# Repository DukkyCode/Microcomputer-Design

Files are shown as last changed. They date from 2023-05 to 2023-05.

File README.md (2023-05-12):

# Microcomputer Design
Introduction:
-	The goal of this project is to design, build, and program a single-board computer. It also provides insight into computer architecture

Chip Specification:
- XR68C681CJ-F – DUART: the XR68C681 devices offers a single IC solution for the 68000 family of microprocessors.
- U62256ADK07LLG – RAM: Static RAM 32K x 8-Bit High Speed CMOS 150ns DIP -28
- AT28C256-15PU – ROM: Memory & Data Storage (EEPROM IC EEPROM 256k 50NS 28DIP) 
- Max232E: IC Transceiver 2 channel 16DIP to interface with DUART
- LD1085V50 – Voltage Regulator: Step 9V down to 5V to provide power for the entire board
- JS202011SCQN – Power Switch: Switch to turn on & off power
- B3F-1022 – Reset Button: Simple power button to activate RESET on the buttons
-	A-DS 09 A/KG-T2S – D-SUB connector: create serial communications with the desktop
-	PJ-002B – Barrel Plug: Barrel Connector to connect with power adapter
- ECS-2200B-080: Create 8MHz clock signal for the CPLD & CPU
- ECS-2100AX-036: Create 3.6MHz clock signal for the DUART chips
- 22-28-4061: J-TAG connector to program the CPLD

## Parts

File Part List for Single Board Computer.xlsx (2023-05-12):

Part | Part Number | Pins | Package | Quantity | Note | Reason | Part Links
Processor | MC68000FN10 | 68 | PLCC | 1 | Bought |  | https://www.ebay.com/itm/401212928938
CPLD | XC9572-10PC84C84 | 84 | PLCC | 1 | Bought |  | https://www.ebay.com/itm/1pcs-XC9572-7PC84C-PLCC-84-XC9572-In-System-Programmable-CPLD-/322563102028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
DUART | SCC68681C1A44 | 44 | PLCC | 1 | New site | The previous seller is out until close March | https://www.ebay.com/itm/392316632455
RAM | U62256ADK07LLG1 | 28 | DIP | 2 | New site | Unavailable | https://www.worldwayelec.com/pro/alliance-memory/u62256adk07llg1/337553?from=octopart
ROM | AT28C256-15PU | 28 | DIP | 2 | New site | Digikey has a different package type | https://www.mouser.com/ProductDetail/Omron-Automation-and-Safety/AT28C256-15PU-ND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
RS232 Driver | Max232E | 16 | DIP | 1 | Still available |  | https://www.digikey.com/en/products/detail/texas-instruments/MAX232ECN/1511013 (https://www.mouser.com/ProductDetail/STMicroelectronics/LD1085V50/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)
Voltage Regulator | LD1085V50 | 3 | THT | 1 | Still available |  | https://www.mouser.com/ProductDetail/STMicroelectronics/LD1085V50/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
Power Switch | JS202011SCQN | 6 | DIP | 1 | Still available |  | https://www.digikey.com/en/products/detail/c-k/JS202011SCQN/2094299
Reset Button | B3F-1022 | 4 | DIP | 1 | Still available |  | https://www.digikey.com/en/products/detail/omron-electronics-inc-emc-div/B3F-1022/44674
D-SUB Connector | A-DS 09 A/KG-T2S | 9 | DIP | 1 | Still available |  | https://www.digikey.com/en/products/detail/assmann-wsw-components/A-DS-09-A-KG-T2S/1241804
Barrel Plug | PJ-002B | 2 | DIP | 1 | Still available |  | https://www.digikey.com/en/products/detail/cui-inc/PJ-002B/96965
CPU/CPLD Clock | VF150-8.000000MHz | 4 | DIP | 1
DUART Clock | ECS-2100AX-036 | 4 | DIP | 1 | Still available |  | https://www.digikey.com/en/products/detail/ecs-inc/ECS-2100AX-036/827265
JTAG Connector | 22-28-4061 | 6 | DIP | 1 | New site |  | https://www.digikey.com/en/products/detail/molex/0022284061/313861?s=N4IgTCBcDa5gtGAHPALABgGwEYQF0BfIA
LEDs | APT3216QBC/D | 2 | SMD | 25 | Still available |  | https://www.mouser.com/ProductDetail/Kingbright/APT3216QBC-D?qs=sGAEpiMZZMseGfSY3csMkfEK84xZfg2SgloFr7gwbO4%3D
0805 1k Resistors | 603-RC0805FR-071KL | 2 | SMD | 20 | Still available |  | https://www.mouser.com/productdetail/yageo/rc0805fr-071kl?qs=sGAEpiMZZMvdGkrng054txdMlaQGj9fiG8OYDyT2iio%3D
0805 330 Resistors | RC0805FR-07330RL | 2 | SMD | 25 - for LEDs | New site | Old website out of stock | https://www.digikey.com/en/products/detail/yageo/RC0805FR-07330RL/727866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
0805 4.7k Resistors | RC0805FR-074K7L | 2 | SMD | 5 | New site | Old website out of stock | https://www.digikey.com/en/products/detail/yageo/RC0805FR-074K7L/727929
0805 1 uF Capacitors | CC0805KKX7R5BB105 | 2 | SMD | 20 | New site | Old website out of stock | https://www.digikey.com/en/products/detail/yageo/CC0805KKX7R5BB105/5884152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
0805 10 uF Capacitors | CC0805KFX5R5BB106 | 2 | SMD | 2 | New site | Old website out of stock | https://www.digikey.com/en/products/detail/yageo/CC0805KFX5R5BB106/14286468
Test Points | 5011 | 1 | DIP | 50 | Still available |  | https://www.digikey.com/products/en?keywords=36-5011-ND
Supervisor chips |  |  |  |  | Optional -depends if the class is using the supervisor chip in case of troubleshooting
Processor Socket | 8468-11B1-RK-TP | 68 | PLCC TO DIP | 1 | Still available |  | https://www.mouser.com/ProductDetail/3M-Electronic-Solutions-Division/8468-11B1-RK-TP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
CPLD Socket | 8484-11B1-RK-TP | 84 | PLCC TO DIP | 1 | Still available |  | https://www.mouser.com/ProductDetail/3M-Electronic-Solutions-Division/8484-11B1-RK-TP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
DUART Socket | 8444-11B1-RK-TP | 44 | PLCC TO DIP | 1 | Still available |  | https://www.mouser.com/ProductDetail/3M-Electronic-Solutions-Division/8444-11B1-RK-TP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
RAM Socket | 4-1571552-9 | 28 | DIP TO DIP | 2 | New site | Old website out of stock | https://www.digikey.com/en/products/detail/te-connectivity-amp-connectors/4-1571552-9/2055977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
ROM Socket | 228-3345 | 28 | DIP TO DIP - ZIF | 2 (comes in 2 pack) | New site - Limited Stock | Out of stock - Amazon $17 and Jameco $10 | https://www.amazon.com/Aries-28-526-10-Connector-Position-Through-Hole/dp/B00B886OLW | https://www.jameco.com/z/28-526-10-Aries-Electronics-ZIF-Socket-28-Position-2-54mm-Solder-Straight-Thru-Hole_102745.html
RS232 Driver Socket | 2-1571552-4 | 16 | DIP TO DIP | 1 | New site | Old website out of stock | https://www.ebay.com/itm/383202106349?hash=item5938a01bed:g:JvEAAOSwBzdgUdBe

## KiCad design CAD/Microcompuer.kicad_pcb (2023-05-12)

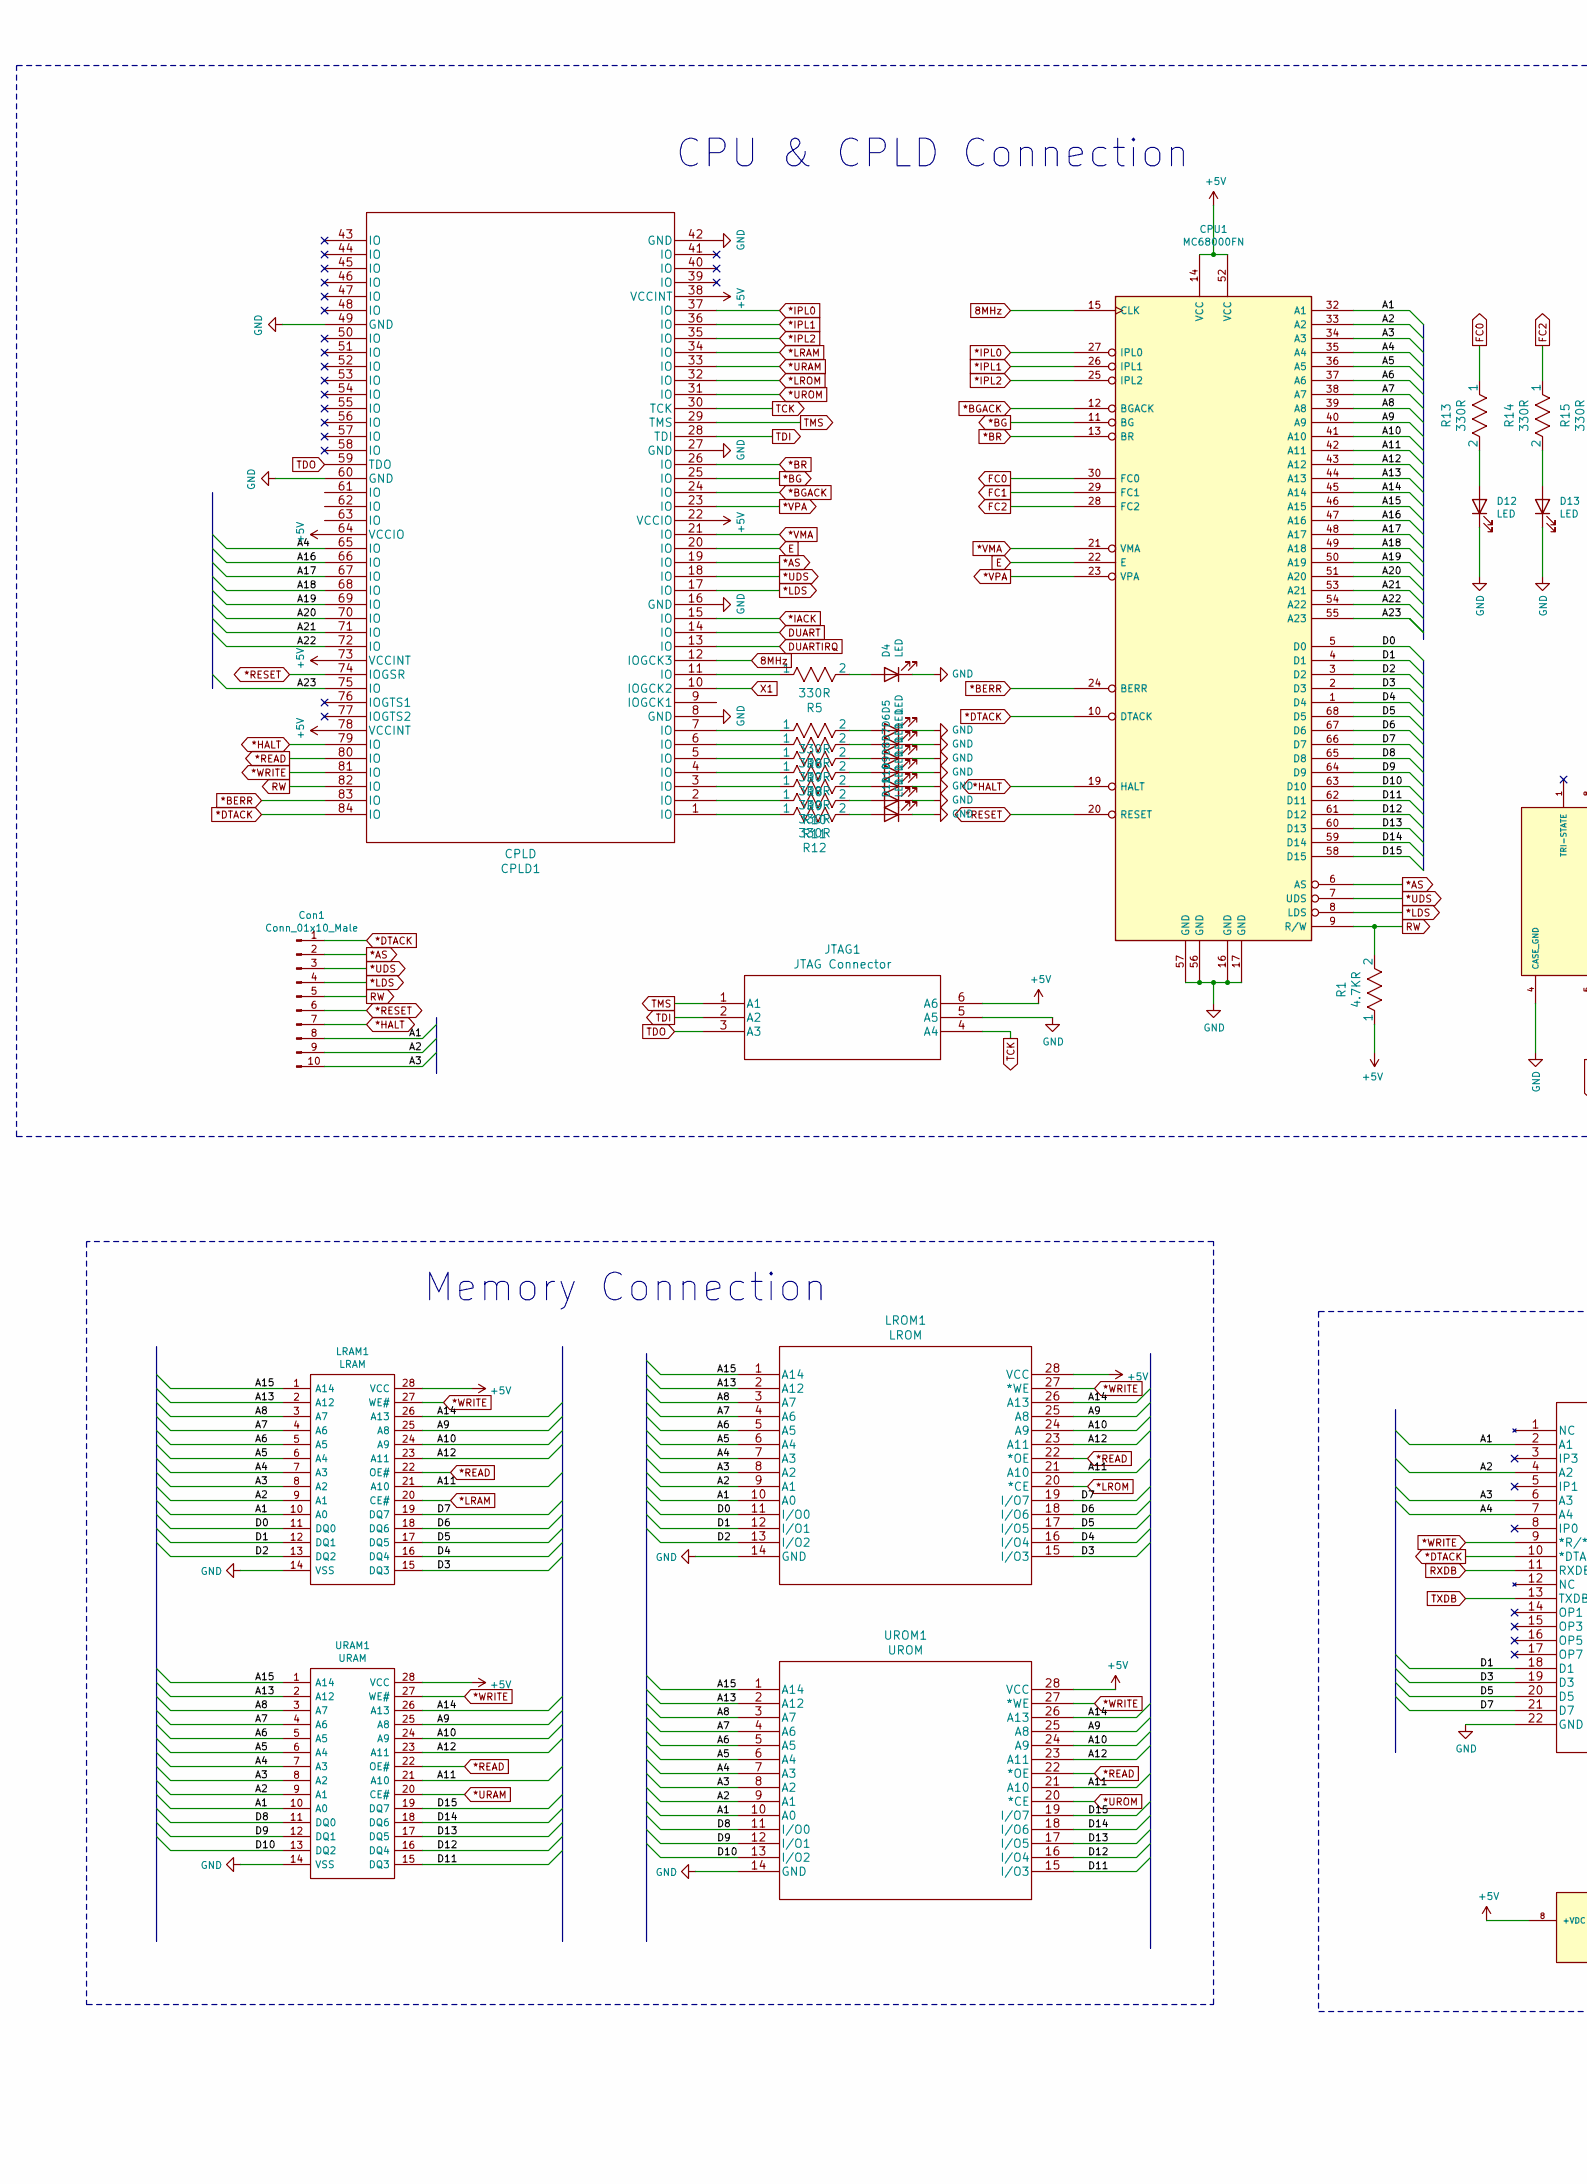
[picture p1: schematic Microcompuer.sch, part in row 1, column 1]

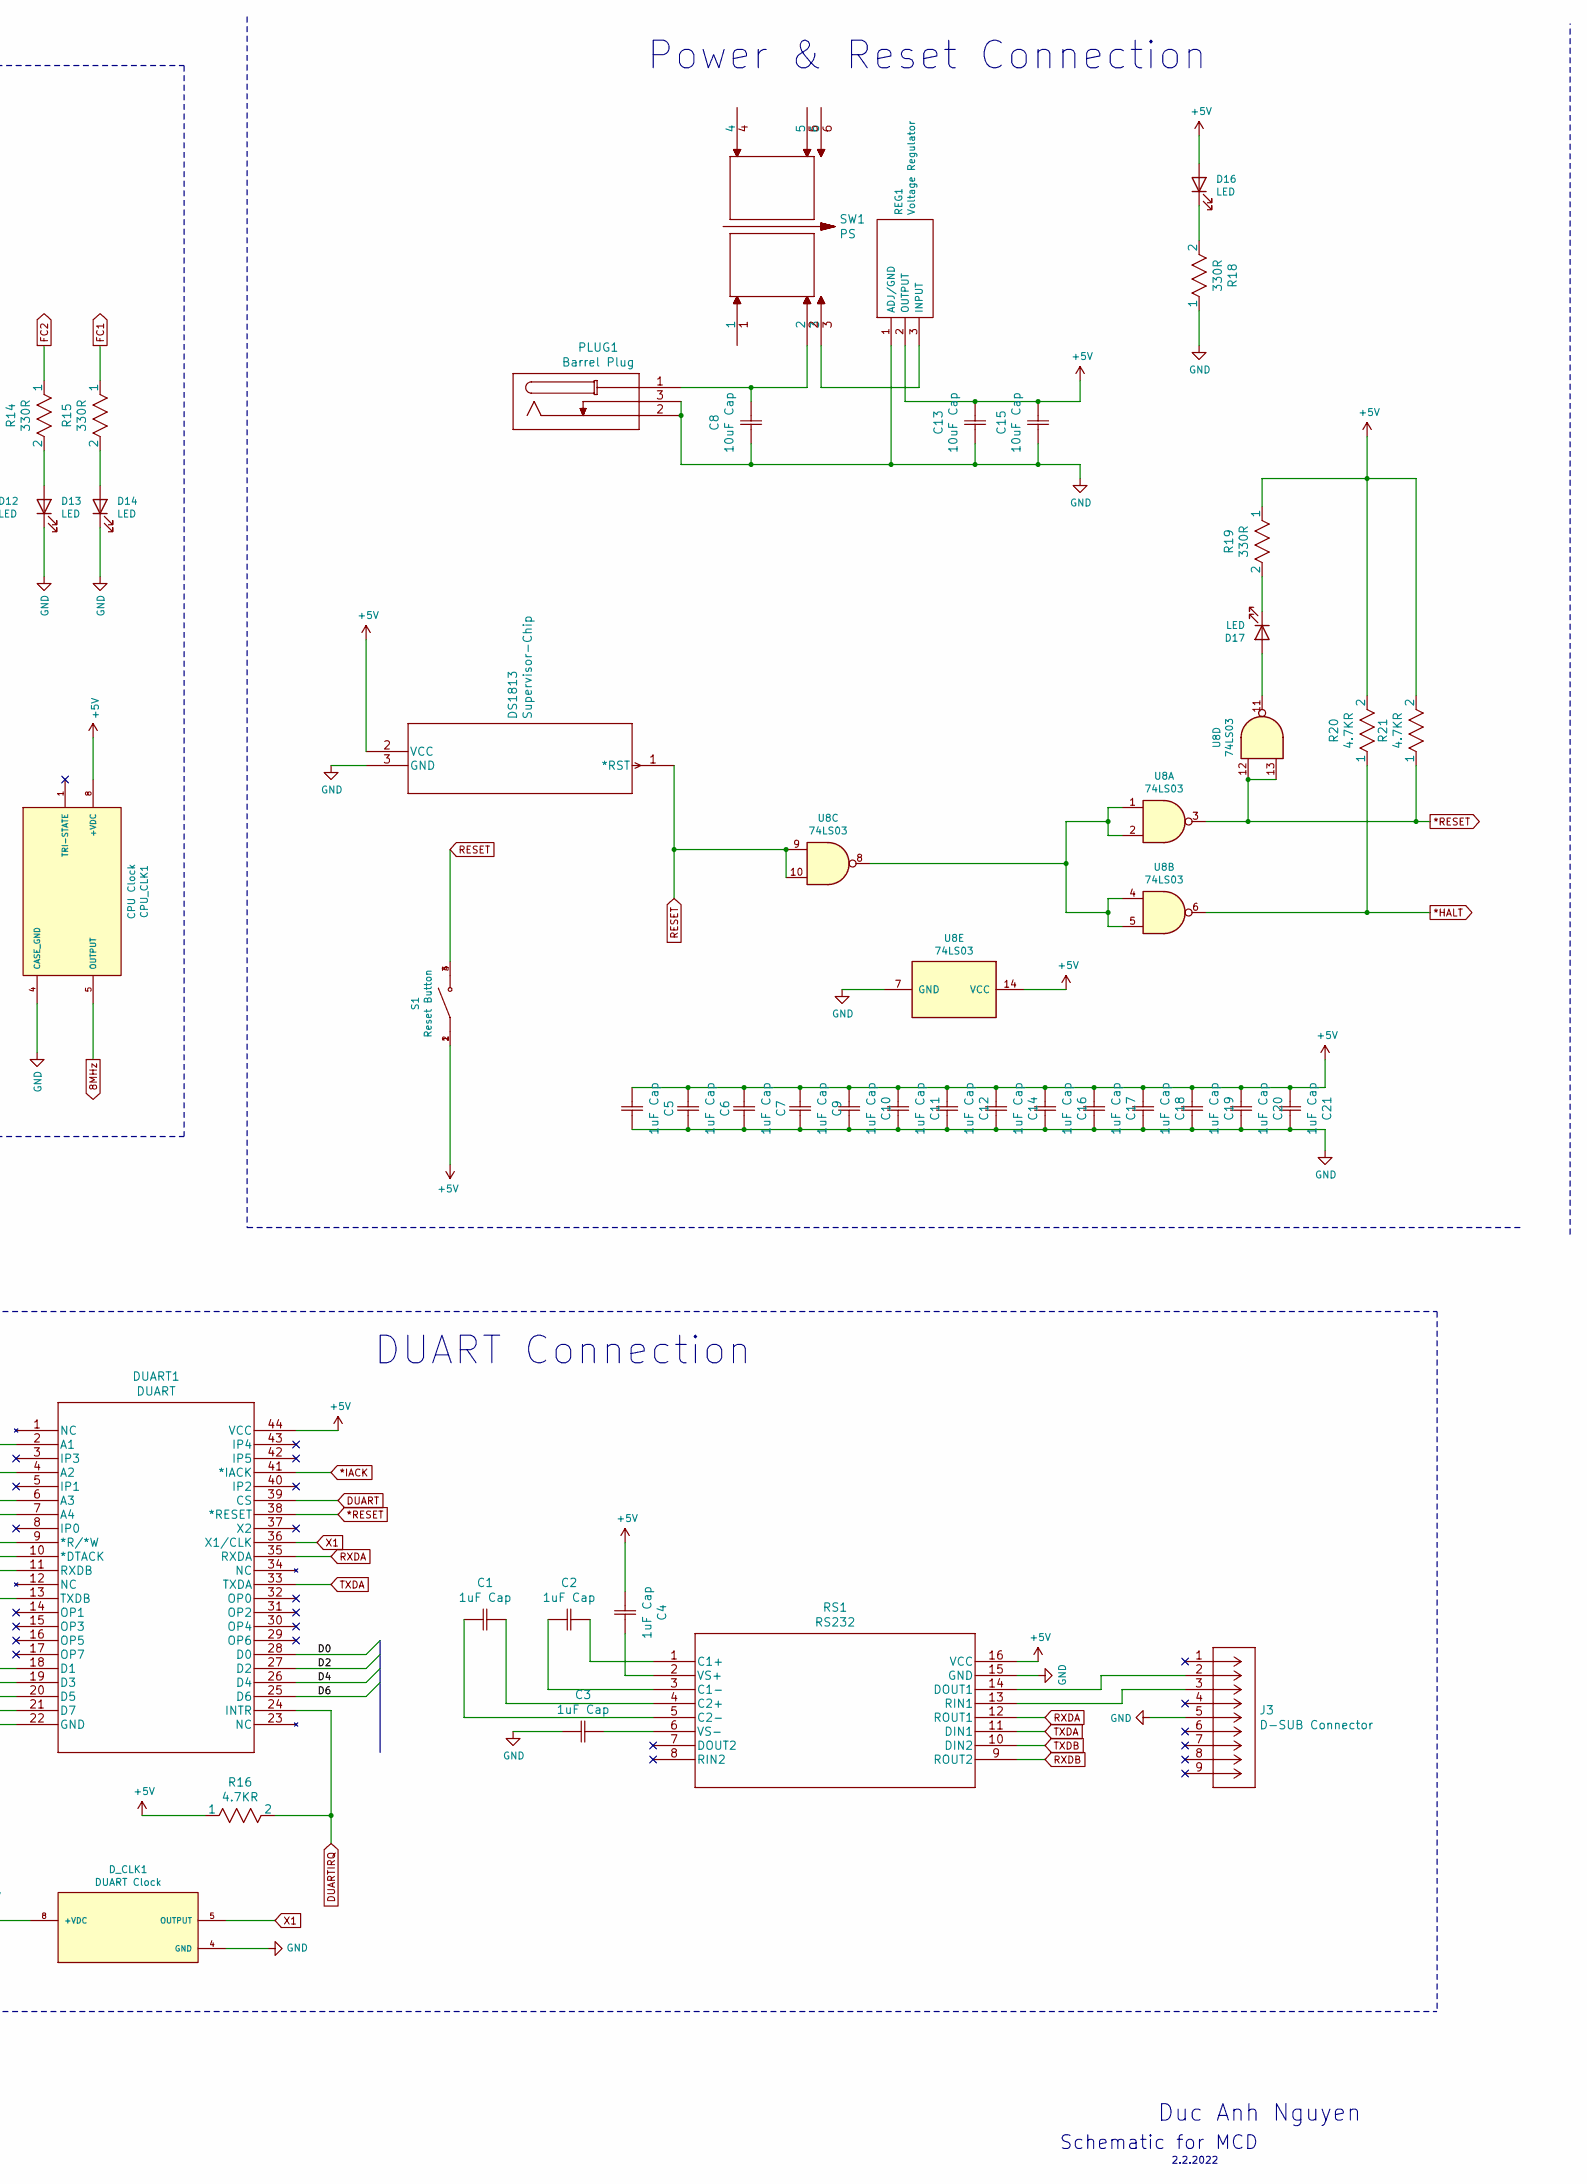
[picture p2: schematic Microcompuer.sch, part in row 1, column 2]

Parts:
C1, C2, C3, C4, C5, C6, C7, C9, C10, C11, C12, C14, C16, C17, C18, C19, C20, C21: 1uF Cap; CC0805KKX7R5BB105
C8, C13, C15: 10uF Cap; CC0805KPX5R5BB106
CPLD1: CPLD; PLCC-84_THT-Socket
CPU1: MC68000FN; PLCC-68_THT-Socket
CPU_CLK1: CPU Clock; OSC_ECS-2200B-080; PARTREV N/A
Con1: Conn_01x10_Male; PinHeader_1x10_P2.54mm_Vertical
D4, D5, D6, D7, D8, D9, D10, D11, D12, D13, D14, D16, D17: LED; LEDC2012X80N
DS1813: Supervisor-Chip; 21-0248A
DUART1: DUART; PLCC-44_THT-Socket
D_CLK1: DUART Clock; OSC_ECS-2100AX-036; PARTREV N/A
J3: D-SUB Connector; DSUB-9_Male_Horizontal_P2.77x2.84mm_EdgePinOffset4.94mm_Hou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
JTAG1: JTAG Connector; 22284061
LRAM1: LRAM; DIP-28_W15.24mm_Socket; Manufacturer_Part_Number AS6C62256-55PCN; Mouser Part Number 913-AS6C62256-55PCN
LROM1: LROM; DIP-28_W15.24mm_Socket
PLUG1: Barrel Plug; BarrelJack_CUI_PJ-102AH_Horizontal
R1, R16, R20, R21: 4.7KR; RC0805FR-074K7L
R5, R6, R7, R8, R9, R10, R11, R12, R13, R14, R15, R18, R19: 330R; RC0805FR-07330RL
REG1: Voltage Regulator; TO255P460X1020X2008-3P; Manufacturer_Part_Number LD1085V50; Mouser Part Number 511-LD1085V50
RS1: RS232; MAX232ECN
S1: Reset Button; SW_B3F-1022; PARTREV O
SW1: PS; JS202011SCQN
U8: 74LS03; SN74LS03N
URAM1: URAM; DIP-28_W15.24mm_Socket; Manufacturer_Part_Number AS6C62256-55PCN; Mouser Part Number 913-AS6C62256-55PCN
UROM1: UROM; DIP-28_W15.24mm_Socket

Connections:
8MHz: CPLD1.12 (IOGCK3), CPU1.15 (CLK), CPU_CLK1.5 (OUTPUT)
*AS: CPLD1.19 (IO), CPU1.6 (AS), Con1.2
*BERR: CPLD1.83 (IO), CPU1.24 (BERR)
*BG: CPLD1.25 (IO), CPU1.11 (BG)
*BGACK: CPLD1.24 (IO), CPU1.12 (BGACK)
*BR: CPLD1.26 (IO), CPU1.13 (BR)
*DTACK: CPLD1.84 (IO), CPU1.10 (DTACK), Con1.1, DUART1.10 (*DTACK)
*HALT: CPLD1.79 (IO), CPU1.19 (HALT), Con1.7, R20.1, U8.6
*IACK: CPLD1.15 (IO), DUART1.41 (*IACK)
*IPL0: CPLD1.37 (IO), CPU1.27 (IPL0)
*IPL1: CPLD1.36 (IO), CPU1.26 (IPL1)
*IPL2: CPLD1.35 (IO), CPU1.25 (IPL2)
*LDS: CPLD1.17 (IO), CPU1.8 (LDS), Con1.4
*LRAM: CPLD1.34 (IO), LRAM1.20 (CE#)
*LROM: CPLD1.32 (IO), LROM1.20 (*CE)
*READ: CPLD1.80 (IO), LRAM1.22 (OE#), LROM1.22 (*OE), URAM1.22 (OE#), UROM1.22 (*OE)
*RESET: CPLD1.74 (IOGSR), CPU1.20 (RESET), Con1.6, DUART1.38 (*RESET), R21.1, U8.3, U8.12, U8.13
*UDS: CPLD1.18 (IO), CPU1.7 (UDS), Con1.3
*URAM: CPLD1.33 (IO), URAM1.20 (CE#)
*UROM: CPLD1.31 (IO), UROM1.20 (*CE)
*VMA: CPLD1.21 (IO), CPU1.21 (VMA)
*VPA: CPLD1.23 (IO), CPU1.23 (VPA)
*WRITE: CPLD1.81 (IO), DUART1.9 (*R/*W), LRAM1.27 (WE#), LROM1.27 (*WE), URAM1.27 (WE#), UROM1.27 (*WE)
/A1: CPU1.32 (A1), Con1.8, DUART1.2 (A1), LRAM1.10 (A0), LROM1.10 (A0), URAM1.10 (A0), UROM1.10 (A0)
/A2: CPU1.33 (A2), Con1.9, DUART1.4 (A2), LRAM1.9 (A1), LROM1.9 (A1), URAM1.9 (A1), UROM1.9 (A1)
/A3: CPU1.34 (A3), Con1.10, DUART1.6 (A3), LRAM1.8 (A2), LROM1.8 (A2), URAM1.8 (A2), UROM1.8 (A2)
/A4: CPLD1.65 (IO), CPU1.35 (A4), DUART1.7 (A4), LRAM1.7 (A3), LROM1.7 (A3), URAM1.7 (A3), UROM1.7 (A3)
/A5: CPU1.36 (A5), LRAM1.6 (A4), LROM1.6 (A4), URAM1.6 (A4), UROM1.6 (A4)
/A6: CPU1.37 (A6), LRAM1.5 (A5), LROM1.5 (A5), URAM1.5 (A5), UROM1.5 (A5)
/A7: CPU1.38 (A7), LRAM1.4 (A6), LROM1.4 (A6), URAM1.4 (A6), UROM1.4 (A6)
/A8: CPU1.39 (A8), LRAM1.3 (A7), LROM1.3 (A7), URAM1.3 (A7), UROM1.3 (A7)
/A9: CPU1.40 (A9), LRAM1.25 (A8), LROM1.25 (A8), URAM1.25 (A8), UROM1.25 (A8)
/A10: CPU1.41 (A10), LRAM1.24 (A9), LROM1.24 (A9), URAM1.24 (A9), UROM1.24 (A9)
/A11: CPU1.42 (A11), LRAM1.21 (A10), LROM1.21 (A10), URAM1.21 (A10), UROM1.21 (A10)
/A12: CPU1.43 (A12), LRAM1.23 (A11), LROM1.23 (A11), URAM1.23 (A11), UROM1.23 (A11)
/A13: CPU1.44 (A13), LRAM1.2 (A12), LROM1.2 (A12), URAM1.2 (A12), UROM1.2 (A12)
/A14: CPU1.45 (A14), LRAM1.26 (A13), LROM1.26 (A13), URAM1.26 (A13), UROM1.26 (A13)
/A15: CPU1.46 (A15), LRAM1.1 (A14), LROM1.1 (A14), URAM1.1 (A14), UROM1.1 (A14)
/A16: CPLD1.66 (IO), CPU1.47 (A16)
/A17: CPLD1.67 (IO), CPU1.48 (A17)
/A18: CPLD1.68 (IO), CPU1.49 (A18)
/A19: CPLD1.69 (IO), CPU1.50 (A19)
/A20: CPLD1.70 (IO), CPU1.51 (A20)
/A21: CPLD1.71 (IO), CPU1.53 (A21)
/A22: CPLD1.72 (IO), CPU1.54 (A22)
/A23: CPLD1.75 (IO), CPU1.55 (A23)
/D0: CPU1.5 (D0), DUART1.28 (D0), LRAM1.11 (DQ0), LROM1.11 (I/O0)
/D1: CPU1.4 (D1), DUART1.18 (D1), LRAM1.12 (DQ1), LROM1.12 (I/O1)
/D2: CPU1.3 (D2), DUART1.27 (D2), LRAM1.13 (DQ2), LROM1.13 (I/O2)
/D3: CPU1.2 (D3), DUART1.19 (D3), LRAM1.15 (DQ3), LROM1.15 (I/O3)
/D4: CPU1.1 (D4), DUART1.26 (D4), LRAM1.16 (DQ4), LROM1.16 (I/O4)
/D5: CPU1.68 (D5), DUART1.20 (D5), LRAM1.17 (DQ5), LROM1.17 (I/O5)
/D6: CPU1.67 (D6), DUART1.25 (D6), LRAM1.18 (DQ6), LROM1.18 (I/O6)
/D7: CPU1.66 (D7), DUART1.21 (D7), LRAM1.19 (DQ7), LROM1.19 (I/O7)
/D8: CPU1.65 (D8), URAM1.11 (DQ0), UROM1.11 (I/O0)
/D9: CPU1.64 (D9), URAM1.12 (DQ1), UROM1.12 (I/O1)
/D10: CPU1.63 (D10), URAM1.13 (DQ2), UROM1.13 (I/O2)
/D11: CPU1.62 (D11), URAM1.15 (DQ3), UROM1.15 (I/O3)
/D12: CPU1.61 (D12), URAM1.16 (DQ4), UROM1.16 (I/O4)
/D13: CPU1.60 (D13), URAM1.17 (DQ5), UROM1.17 (I/O5)
/D14: CPU1.59 (D14), URAM1.18 (DQ6), UROM1.18 (I/O6)
/D15: CPU1.58 (D15), URAM1.19 (DQ7), UROM1.19 (I/O7)
DUART: CPLD1.14 (IO), DUART1.39 (CS)
DUARTIRQ: CPLD1.13 (IO), DUART1.24 (INTR), R16.2
E: CPLD1.20 (IO), CPU1.22 (E)
FC0: CPU1.30 (FC0), R13.1
FC1: CPU1.29 (FC1), R15.1
FC2: CPU1.28 (FC2), R14.1
unnamed: C1.1, RS1.5 (C2-)
unnamed: C1.2, RS1.4 (C2+)
unnamed: C2.1, RS1.3 (C1-)
unnamed: C2.2, RS1.1 (C1+)
unnamed: C3.2, RS1.6 (VS-)
unnamed: C4.2, RS1.2 (VS+)
unnamed: C8.2, PLUG1.1, SW1.2
unnamed: CPLD1.1 (IO), R12.1
unnamed: CPLD1.2 (IO), R11.1
unnamed: CPLD1.3 (IO), R10.1
unnamed: CPLD1.4 (IO), R9.1
unnamed: CPLD1.5 (IO), R8.1
unnamed: CPLD1.6 (IO), R7.1
unnamed: CPLD1.7 (IO), R6.1
unnamed: CPLD1.11 (IO), R5.1
unnamed: D4.2 (A), R5.2
unnamed: D5.2 (A), R6.2
unnamed: D6.2 (A), R7.2
unnamed: D7.2 (A), R8.2
unnamed: D8.2 (A), R9.2
unnamed: D9.2 (A), R10.2
unnamed: D10.2 (A), R11.2
unnamed: D11.2 (A), R12.2
unnamed: D12.2 (A), R13.2
unnamed: D13.2 (A), R14.2
unnamed: D14.2 (A), R15.2
unnamed: D16.1 (K), R18.2
unnamed: D17.1 (K), R19.2
unnamed: D17.2 (A), U8.11
unnamed: DS1813.1 (*RST), S1.3, S1.4, U8.9, U8.10
unnamed: J3.2, RS1.14 (DOUT1)
unnamed: J3.3, RS1.13 (RIN1)
unnamed: REG1.3 (INPUT), SW1.3
unnamed: U8.1, U8.2, U8.4, U8.5, U8.8
RW: CPLD1.82 (IO), CPU1.9 (R/W), Con1.5, R1.2
RXDA: DUART1.35 (RXDA), RS1.12 (ROUT1)
RXDB: DUART1.11 (RXDB), RS1.9 (ROUT2)
TCK: CPLD1.30 (TCK), JTAG1.4 (A4)
TDI: CPLD1.28 (TDI), JTAG1.2 (A2)
TDO: CPLD1.59 (TDO), JTAG1.3 (A3)
TMS: CPLD1.29 (TMS), JTAG1.1 (A1)
TXDA: DUART1.33 (TXDA), RS1.11 (DIN1)
TXDB: DUART1.13 (TXDB), RS1.10 (DIN2)
X1: CPLD1.10 (IOGCK2), DUART1.36 (X1/CLK), D_CLK1.5 (OUTPUT)

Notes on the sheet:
CPU & CPLD Connection
Memory Connection
DUART Connection
Power & Reset Connection
Schematic for MCD
2.2.2022
Duc Anh Nguyen

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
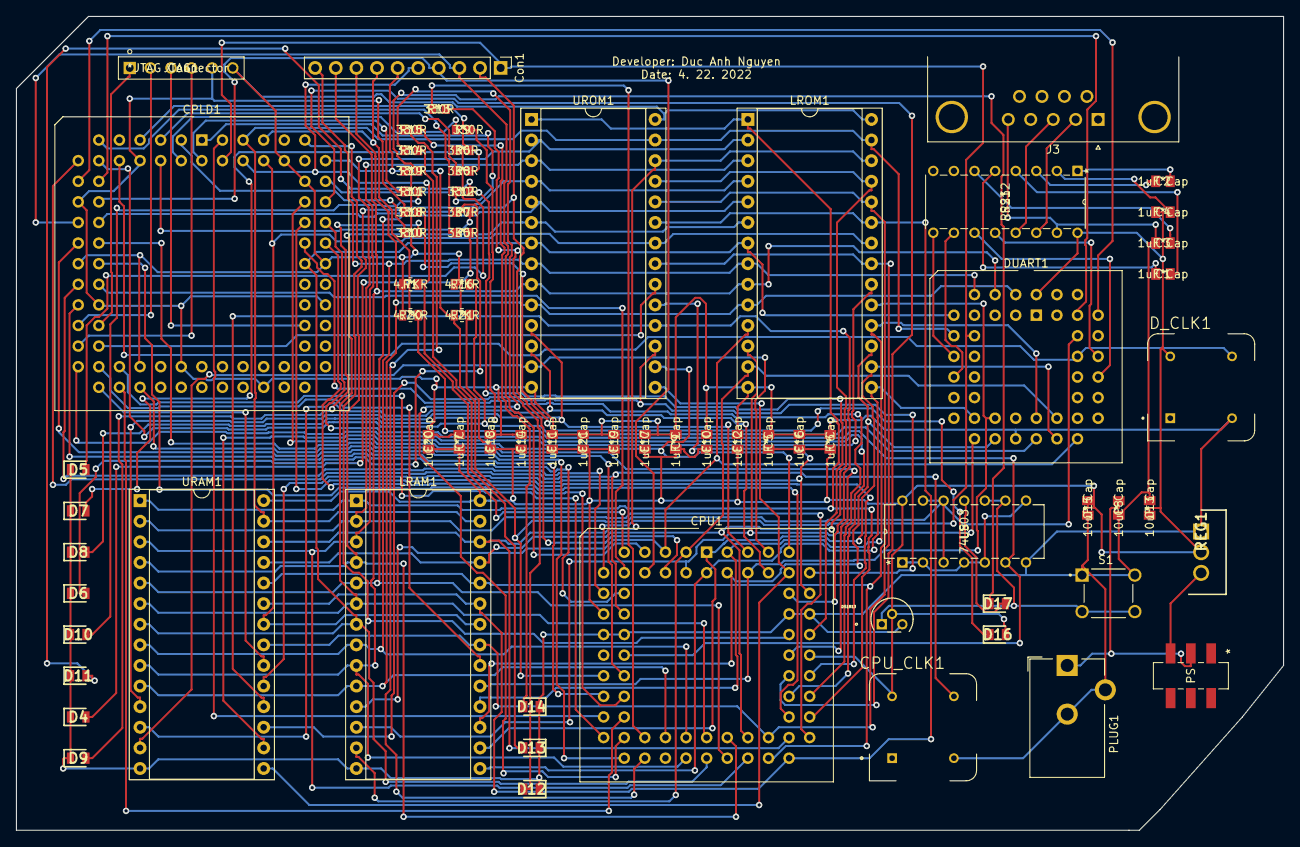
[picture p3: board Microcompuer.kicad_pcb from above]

Board: 2 copper layers, 156.2 x 100.3 mm, 70 parts (0 on the bottom side), 114 nets.

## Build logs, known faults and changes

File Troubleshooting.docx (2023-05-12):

IV – Troubleshooting:

1. Barrel Jack Footprint:
- Wrong Orientation of the footprint – easy fix
- Capacitor for the RS232 is bad =>> hot =>> replace RS232

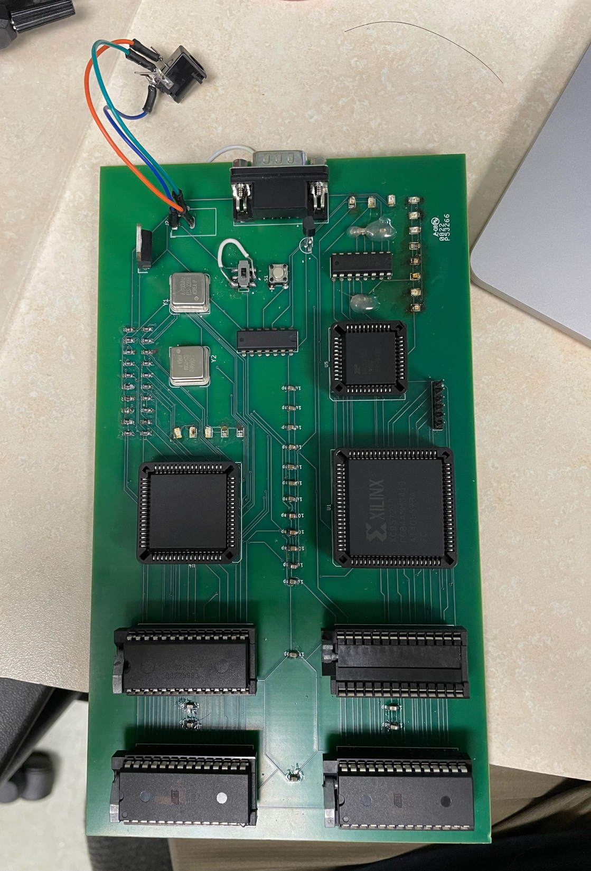
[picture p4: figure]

2. RESET & HALT behavior:
- Reset & halt lines have similar behavior.
- There must be a delay of 150ms to discharge the internal capacitors of the CPU.
- These 2 lines are driven by the hardware.
- Connecting other peripheral devices causes the CPU to halt the simulator – discuss later.
- Problem:
  - Reset Buttons are being driven high =>> which makes the open-collector buffer being useless =>> cannot pull reset & halt line low
  - It does not match the datasheet provided by the DS1813+ Supervisor.
3. Logical Lines Analysis:
- BR, BERR, BG, BGACK is Bus Arbitration line, which only needed if you are controlling lines with CPLD =>> drive them high using CPLD
- Mistakes: Driven RESET & HALT using the CPLD with the current hardware reset setup
- Creates oscillating logical lines =>> bad
- Disconnect RESET & HALT using the CPLD.
- RW should be pulled up by resistor (4.7kΩ)
4. Hardware Check:
- Checking every voltage line coming into your chips =>> issues come from bad CPLD

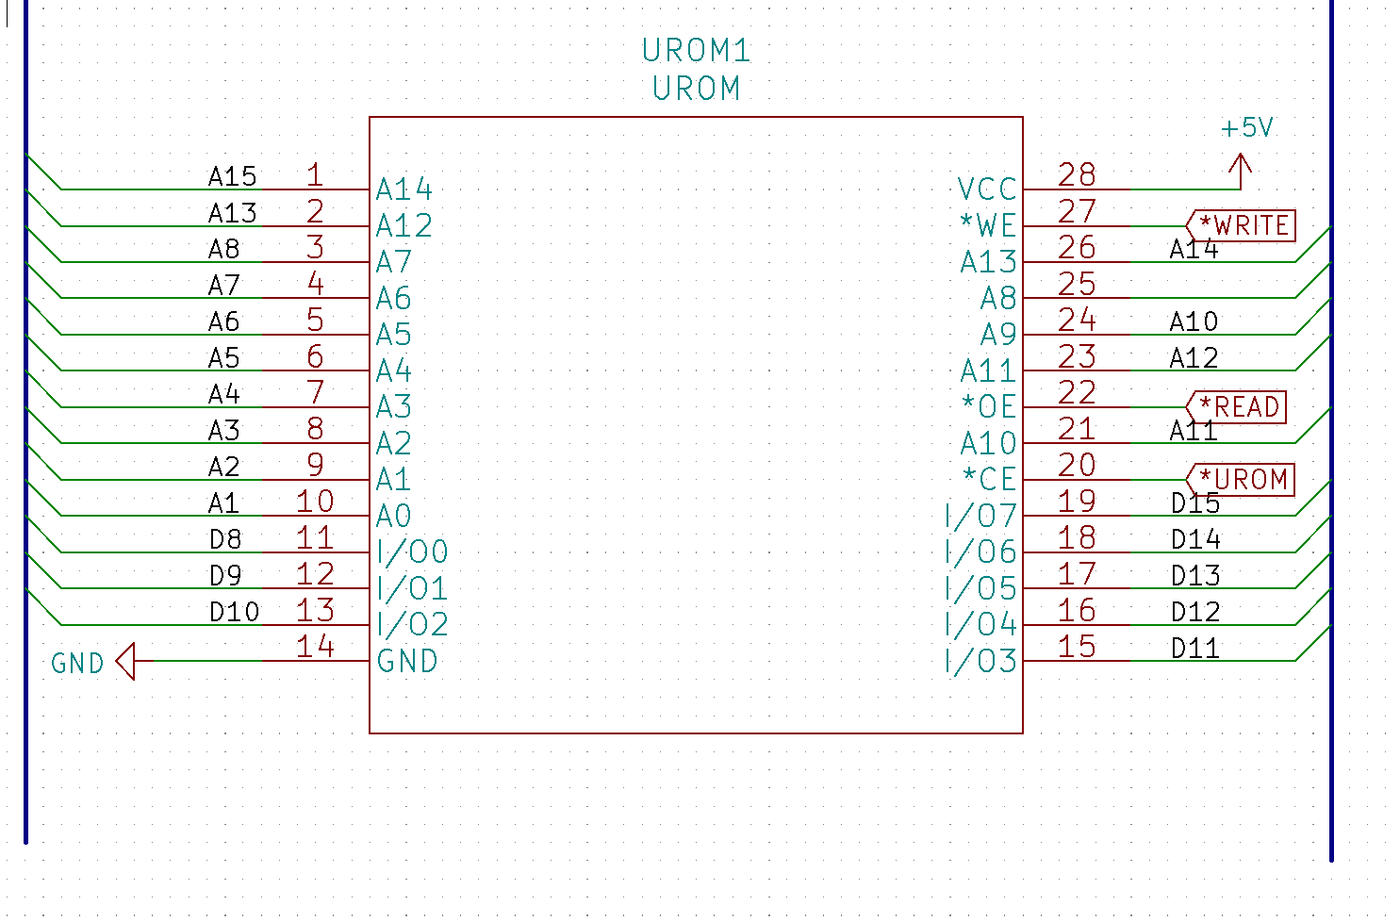
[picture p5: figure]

- Address line A9 never got connected =>> Somehow passed all the hardware test

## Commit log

2023-05-12 Some small changes
    [MCD_pad.csv, Part List for Single Board Computer.xlsx]
2023-05-12 Final Commit
    [MCD_pad.csv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]

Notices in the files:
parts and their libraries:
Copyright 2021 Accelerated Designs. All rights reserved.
